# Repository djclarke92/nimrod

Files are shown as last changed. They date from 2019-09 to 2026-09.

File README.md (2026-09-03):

# Nimrod Home Automation

A home automation project based on the Raspberry Pi, Modbus IO devices and NodeMCU modules.  The control software is written in C++ and the web configuration is in PHP7.  Relies on 
a MySQL database running on a separate host.  The current software is compiled for Pi model B running the Rasbian buster release.

Why call it Nimrod ?  It needed a name and "Nimrod" was the name of a neanderthal butler in an early Doctor Who episode. The original purpose was to develop something to turn on my
motorbike glove heater 30 minutes before my morning alarm went off if the outside temperature was below 15 deg C.

The Nimrod software is compiled on your standard linux desktop PC, then cross compiled for the Pi version your are using.  In theory you could compile everything on the Pi and 
do away with the cross compiler step.

Uses dygraph.js from http://dygraphs.com for displaying graphs. Websocket support comes from https://libwebsockets.org/.

What can you do with it ?
* Input events can be switches, temperature values, voltage levels or time of day
* Turn on one or more output ports when an input event occurs
* Input switch events can be a click, double click or long click, each can trigger different output actions
* Input events can be chained together, e.g. if time is 6:30am and temperature sensor #2 is < 15 deg then turn on output #7 for 30 minutes
* Complex processes can be managed by the integratd PLC State Machine

Communication with each modbus device is polled.  All digital inputs are active low, i.e. connect to 0V / Gnd to activate.  All digital outputs are active low open collector outputs.

On a Pi4, we recommend that you move the /var file system onto a USB3 hard drive otherwise the Pi's uSDHC card will die quite soon due to the number of writes. 

The Nimrod web page also supports displaying CCTV camera images and video streams, to do this you need the mount the CCTV image storage filesystem onto the Pi (edit /etc/fstab and 
create /etc/.smbpwd).  The camera definitions are in the file/site_config.conf file.
1.	/etc/fstab example
	//<SERVER_IP_ADDRESS>/cctv  /cctv   cifs    auto,gid=users,file_mode=0660,dir_mode=0660,iocharset=utf8,credentials=/etc/.smbpwd  0 0
2.	/etc/.smbpwd example, mode must be 0600
	username=<some_user_name>
	password=<some_password>
	domain=YOURSMBWORKGROUP

Note that for each server using a guest account, you may wish to specify an additional share in /etc/samba/smb.conf
thus;

[cctv]
        comment = cctv
        inherit acls = Yes
        path = /cctv
        read only = No
        vfs objects =
[cctv2]
        comment = cctv2
        inherit acls = Yes
        path = /cctv
        read only = No
        vfs objects =

Add a share for each additional server that will connect using the same account. In /etc/fstab, specifiy the new share name for each additional server
//<SERVER_IP_ADDRESS/cctv2, etc

This works around some Windows/samba peculiarities and allows conflict-free file/directory access.

Alternatively, you could use NFS instead, if you aren't using Windows PC's to access the camera files.

## Devices, Device Info and IO Links

Each Modbus interface device is called a "Device" in Nimrod speak.  So a "Device" could be a 16 digital input unit, 8 relay output unit, 8 analog voltage input unit, etc.

Once you have define a device you need to tell Nimrod what each of it's ports is connected to, this is called the "Device Info".  So for a 16DI unit you would setup input channel 1 is 
"Kitchen switch 1", input channel 2 is "Lounge switch 1", etc. The actual connections are determined by the physical cabling between the switch and the Modbus device.  Output devices 
are similarly defined, e.g. 8RO device channel #4 is "Carport Lights".

Now that you have defined the inputs and outputs you need to tell Nimrod how to connect them together.  This is called "IO Links".  E.g. "Kitchen switch 1" links to 
"Carport Lights", and you can also specify if the output is on until the switch is pressed again or automatically turns off after a set time.

## Supported Modbus devices

Modbus RS485 devices from Wellpro and others

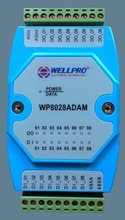
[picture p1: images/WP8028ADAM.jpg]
WP8028ADAM device


* WP3066ADAM		8DS18B20 - 8x DS18B20 temperature inputs
* WP3082ADAM		8AI - 8x 0-20mA / 4-20mA analog inputs
* WP3084ADAM		8VI - 8x 0-10V DC analog inputs
* WP8025ADAM		8RO - 8x relay outputs
* WP8026ADAM		16DI - 16x digital inputs
* WP8027ADAM		16DO - 16x digital outputs
* WP8028ADAM		8DI/8DO - 8x digital outputs, 8x digital inputs
* PD3064			8KT - 8 K Thermocouples
* HDL300			Submersible water level sensor

## Supported WiFi devices

* NodeMCU (ESP8266)
	modules - adc crypto enduser_setup file gpio http net node pwm tmr uart websocket wifi + TLS

# Nimrod package file structure
* ./LICENSE							GNU v3 license
* ./README.md						This file
* ./RELEASE-NOTES.TXT				A history of changes to Nimrod
* ./index.php						Nimrod web portal home page
* ./favicon.ico						Favicon file
* ./bin/nimrod						Nimrod server executable (amd64)
* ./bin/nimrod-arm7					Nimrod server executable (arm7)
* ./bin/set-address					Set the Modbus device index (amd64)
* ./bin/set-address-arm7			Set the Modbus device index (arm7)
* ./files/cameras.php				Shows CCTV camera snapshots on the Nimrod web console
* ./files/class.email.php
* ./files/common.php				Base configuration and some common functions
* ./files/commonhtml.php			Common functions which include HTML output.
* ./files/deviceinfo.php
* ./files/devices.php
* ./files/dygraph.js				Javascript graphing lib
* ./files/dygraph.css				Javascript graphing lib
* ./files/dygraph.min.js			Javascript graphing lib
* ./files/events.php				ToDo
* ./files/home.php
* ./files/intro.php					What is Nimrod
* ./files/monitor.php				Full screen monitor pages 1 and 2
* ./files/iolinks.php
* ./files/site_config.php
* ./files/site_config.php.sample	Example site config file
* ./files/styles.css
* ./images/*						Various image files to make Nimrod look good
* ./scripts/tables.sql				MySQL table creation sql script
* ./scripts/build-num.sh			Update the build number automatically each time makerelease.sh is run
* ./scripts/makerelease.sh			Create a new nimrod package
* ./scripts/nimrod.service			Exampe Nimrod service file of the Pi
* ./scripts/archive_cctv.sh			Script to delete old cctv files
* ./sounds/alerts.mp3
* ./sounds/warning1.mp3
* ./cctv -> /var/cctv				Symlink to your cctv images storage directory
* ./uploads							Create this directory manually and change the owner:group to www-data:www-data

# Raspberry Pi Model 4

## Create Pi bootable SD card

We recommend 16GB SD cards are used, an 8GB card is likely to run out of space in the future.

1.	umount /dev/sdd1
2.	dd bs=4M if=2019-07-10-raspbian-buster.img of=/dev/sdd
3.	boot the pi
	
## Initial Setup of the Pi

- Menu - Pi Configuration
	- System Tab
	- Expand Filesystem
	- Change password for pi user to something new (default is raspberry, nimrod default is passw0rd.23)
	- set hostname to nimrod (or nimrod2, nimrod3, etc)
	- Disable auto login 
- Interfaces Tab
	- Enable SSH
- Localization
	- Set Locale to EN / NZ
	- Set Timezone to Pacific/Auckland
	- Set Keyboard to United States / English International
	- Set WiFi Country to NZ
- Reboot
- Set password for root > sudu su; passwd
- Set static IP address
- sudo vi /etc/dhcpcd.conf (add to the end of the file)
		interface eth0
	  		static ip_address=192.168.1.199/24
	  		static routers=<your_gateway_ip_address>	
	  		static domain_name_servers=<dns_ip_addres_1> <dns_ip_address_2>
	  			(NZ InspireNet DNS servers are 203.114.168.2 203.114.128.2)
- Reboot	
- apt-get update
- apt-get upgrade
- Reboot

## Create the nimrod user on the Pi

It is recommended that you use the same uid/gid for each user/group across your installation. The useradd/groupadd 
commands have options for this.

1.	> adduser nimrod
	- Set password to something
2.	Add nimrod user to the dialout group to give acces to the /dev/ttyUSB* devices
	> adduser nimrod dialout
3.	Add any public ssh keys to $HOME/.ssh/authorized_keys
4.	Create pub/priv key pair
	> ssh-keygen -t rsa
	- copy the public key to nimrod@<database_server>:~/.ssh/authorized_keys

## Install additional packages required by Nimrod on the Pi

- cmd line: sudo apt-get update (update list of available packages)
- gui: sudo aptitude
- example to install curl
	- apt-cache search curl
	- apt-get install curl

Raspbian buster
- apache2 libapache2-mod-php php php-mysql php-gd
- libmodbus5 libmodbus-dev
- libssl-dev libusb-dev ntpddate
- mariadb-server
- mariadb-client libmariadb-dev
- (old mysql-client libmysqlclient-dev)
- msmtp msmtp-mta mailutils
- libwebsockets8 libwebsockets-dev libwebsockets-test-server
- gparted vsftpd

- Secure the mariadb installation
> sudo mysql_secure_installation

- Enable mod-ssl in apache using a self signed certificate
> sudo a2enmod ssl
> sudo a2ensite default-ssl
> sudo systemctl restart apache2

- Remove the default index.html file
> sudo rm /var/www/html/index.html

- make apache a member of the nimrod group
> sudo adduser www-data nimrod

## remove the swap file from the SD card

> sudo dphys-swapfile swapoff
> sudo dphys-swapfile uninstall
> sudo update-rc.d dphys-swapfile remove

## Move the /var directory onto a USB3 drive

- Once you transfer /var onto the USB3 drive the Pi will not boot without the USB3 drive connected
- Don't try and connect a second USB drive, the Pi4 can't cope with that
- Connect and the USB3 drive, format a large ext4 partition and a smaller swap partition
> sudo gparted

- Get the partition uuid's
> sudo blkid /dev/sda1
> sudo blkid /dev/sda2

- Edit the /etc/fstab to add in the new partitions
> sudo vi /etc/fstab
  # /dev/sda1
  PARTUUID=9ee98a25-97e4-xxxx-xxxx-dd0a23e1f247   swap    swap    defaults        0       0
  # /dev/sda2
  PARTUUID=51b819e6-8fd1-xxxx-xxxx-7ffbb871917e   /var    ext4    defaults        0       2
  
- Mount the new var partition and copy the files across
> sudo mount /dev/sda2 /mnt
> sudo rsync -axov /var/* /mnt

- Reboot and your /var partition and swap are on the USB3 drive
> sudo reboot

## Setup msmtp mail on the Pi

> sudo vi /etc/msmtprc
	# Set default values for all following accounts.
	defaults
	logfile /var/tmp/msmtp.log

	# Use the mail submission port 587 instead of the SMTP port 25.
	port 465

	# Always use TLS.
	tls on
	tls_starttls off

	# Set a list of trusted CAs for TLS. The default is to use system settings, but
	# you can select your own file.
	tls_trust_file /etc/ssl/certs/ca-certificates.crt

	# If you select your own file, you should also use the tls_crl_file command to
	# check for revoked certificates, but unfortunately getting revocation lists and
	# keeping them up to date is not straightforward.
	#tls_crl_file ~/.tls-crls

	# Mail account
	# TODO: Use the users username, e.g. root for system and pi for your raspbian user
	account pi

	# Host name of the SMTP server
	# TODO: Use the host of your own mail account
	host <your_isp_mail_host>

	# As an alternative to tls_trust_file/tls_crl_file, you can use tls_fingerprint
	# to pin a single certificate. You have to update the fingerprint when the
	# server certificate changes, but an attacker cannot trick you into accepting
	# a fraudulent certificate. Get the fingerprint with
	# $ msmtp --serverinfo --tls --tls-certcheck=off --host=smtp.freemail.example
	#tls_fingerprint 00:11:22:33:44:55:66:77:88:99:AA:BB:CC:DD:EE:FF:00:11:22:33
	
	# Envelope-from address
	# TODO: Use your own mail address
	from <pi_hostname>@<your_domain>
	
	# Authentication. The password is given using one of five methods, see below.
	auth on
	
	# TODO: Use your own user name for the mail account
	user pi@<your_domain>
	
	# Password method 1: Add the password to the system keyring, and let msmtp get
	# it automatically. To set the keyring password using Gnome's libsecret:
	# $ secret-tool store --label=msmtp \
	#   host smtp.freemail.example \
	#   service smtp \
	#   user joe.smith
	
	# Password method 2: Store the password in an encrypted file, and tell msmtp
	# which command to use to decrypt it. This is usually used with GnuPG, as in
	# this example. Usually gpg-agent will ask once for the decryption password.
	#passwordeval gpg2 --no-tty -q -d ~/.msmtp-password.gpg
	
	# Password method 3: Store the password directly in this file. Usually it is not
	# a good idea to store passwords in plain text files. If you do it anyway, at
	# least make sure that this file can only be read by yourself.
	# TODO: Use the password of your own mail account
	password <email_password>
	
	# Password method 4: Store the password in ~/.netrc. This method is probably not
	# relevant anymore.
	
	# Password method 5: Do not specify a password. Msmtp will then prompt you for
	# it. This means you need to be able to type into a terminal when msmtp runs.
	
	# Set a default account
	# TODO: Use the same account you've configured under account, e.g. root or pi
	account default: pi
	
	# Map local users to mail addresses (for crontab)
	aliases /etc/aliases
	
> sudo chown pi:pi /etc/msmtprc
> sudo chmod 0600 /etc/msmtprc
> sudo chmod 0777 /var/tmp
  cp /etc/msmtprc ~/.msmtprc

> sudo vi /etc/aliases
	root: pi@<your_domain>
	default: pi@<your_domain>
	
> sudo vi /etc/mail.rc
	set sendmail="/usr/bin/msmtp -t"

## Create a certificate so NodeMCU (ESP8266) WiFi devices can connect

> ssh nimrod@nimrod
> openssl req -x509 -nodes -days 3650 -newkey rsa:2048 -keyout nimrod-cert.key -out nimrod-cert.pem

# MySQL Database server

The MySQL database will contain the nimrod configuration and record events and monitoring data.
1.	Create nimrod user with password
2.	Create pub/priv key
	> ssh-keygen -t rsa
3.	Copy pub key to nimrod@pi
4.	Create nimrod database
5.	Create the nimrod tables
	
## Database username and password

If you want to change the default database username or password you need to edit the tables.sql and files/site_config.php files
to specify your required username and password before you create the tables. 
File:	./files/site_config.php			defines DB_USER_NAME and DB_PASSWORD
File:	./scripts/tables.sql			grant select,insert,update,delete on .......
	
## Database ssh tunnel

Nimrod sets up a tunnel to a remote mysql server as per the IP address in the site_config.php file. On the remote mysql host you need to add nimrod as a user and add 
the ssh keys for all nimrod hosts

# Installing Nimrod on the Pi into /var/www/html for the first time

1.	Copy the install tar file from your PC to the Pi
> scp nimrod-x.y.z.tgz nimrod@nimrod:/var/www/html/.
		
2.	Set permissions and untar the package as the nimrod user
> ssh nimrod@nimrod  
> sudo chown -R nimrod:nimrod /var/www/html  
> cd /var/www/html  
> tar xvzf nimrod.x.y.z.tgz  
> cp files/site_config.php.sample files/site_config.php  
> vi site_config.php  
	- set REMOTE_MYSQL_HOST and DB_PASSWORD
	
3.	Establish the SSH tunnel to the database host to accept the host key as the nimrod user
> ssh nimrod@REMOTE_DB_HOST  
> yes  
> ctrl-d		

4.	Create the guest user for camera ftp login
> adduser guest  
	- Set password to something (cameras will use guest/pwd to ftp videos to the server)
> add cctv symlink
	sudo su - guest
	cd /home/guest
	sudo mkdir /var/cctv .
	sudo mkdir /var/cctv/<camera_name>
	sudo chown -R guest:guest /var/cctv

4.	Apache2 setup
> Create the cctv symlink  
	cd /var/www/html  
	sudo ln -s /var/cctv cctv  
> Add apache to the guest group  
	sudo adduser www-data guest  
> Restart apache  
	sudo service apache2 restart

5.	Move the nimrod.log file onto /var/tmp
> cd /home/nimrod  
> sudo ln -s /var/tmp log  
> sudo vi /var/www/html/files/site_config.php
			
6.	Add nimrod to the guest group
> sudo adduser nimrod guest

7. create the web uploads directory
> sudo mkdir /var/www/html/uploads  
> sudo chown -R nimrod:nimrod /var/www/html  
> sudo chmod g+w /var/www/html/uploads

8.	Set nimrod to start automatically
> ssh pi@nimrod  
> cd /var/www/html  
> sudo cp scripts/nimrod.service.arm(7 or 64) /lib/systemd/system/nimrod.service  
> sudo chown root:root /lib/systemd/system/nimrod.service  
> sudo systemctl enable nimrod.service  
> sudo systemctl start nimrod

9.	Setup vsftpd if you have cameras attached so nimrod and apache can view the video files
> sudo vi /etc/vsftpd.conf  
  write_enable=YES  
  local_umask=002  
> sudo vi /home/guest/.bashrc  
  umask 002
  sudo systemctl restart vsftpd

10.	Nimrod should now be running

See the log in /home/nimrod/nimrod.log.  Point your browser to https://nimrod/index.php
	
11. Add a crontab entry for the nimrod user to archive old cctv files

> 20 4 * * * /home/nimrod/bin/archive_cctv.sh 2>&1

#Installing a signed ssl cert for apache2

See https://peppe8o.com/use-lets-encrypt-and-certbot-to-secure-raspberry-pi-hosted-websites-automatically/ for details
This gives you a 3 month signed certificate

> sudo apt update  
> sudo apt install snapd  
> sudo reboot  
> sudo snap install core  s
> sudo snap refresh core

># remove certbot if it is already installed
> sudo apt remove certbot

> sudo snap install --classic certbot  
> sudo ln -s /snap/bin/certbot /usr/bin/certbot  
> sudo certbot --apache -d <your_domain_name> -d www.<your_domain_name>

To renew the certificate use the following command
> sudo certbot renew

# Setup the cross compiler environment on your linux desktop PC

On your linux desktop PC:
> cd $HOME  
> mkdir raspberrypi  
> cd raspberrypi  
> rsync -rl --delete-after --copy-unsafe-links --progress pi@nimrod:/{lib,usr} $HOME/raspberrypi/rootfs

# Download the raspberrypi tools from github

cd $HOME/raspberrypi

> git clone https://github.com/raspberrypi/tools

# Download the raspberrypi documentation from github 

> git clone https://github.com/raspberrypi/documentation

- add to .bashrc
export PATH=$PATH:$HOME/raspberrypi/tools/arm-bcm2708/gcc-linaro-arm-linux-gnueabihf-raspbian/bin
	
Add gcc/g++ compiler packages to your desktop including 32bit gcc support packages, lib32gcc-6-dev, lib32z1

# Development and debugging

1.	A fairly verbose log file is written to /home/nimrod/nimrod.log
2.	Check the apache2 logs at /var/log/apache/error.log
3.	The nimrod application will automatically upgrade itself if it sees a nimrod.x.y.x.tgz package file in the /var/www/html directory
	To turn off the automatic upgrade feature, touch the file /var/www/html/no.upgrade
4.	The nimrod application will attempt to create an SSH tunnel to the remote MySQL database host on startup.
	To disable the SSH tunnel, touch the file /var/www/html/no.tunnel
5.	Each modbus device must be set with a unique address (1-254) using the set-address (or set-addres-arm7) tool. 
	A maximum of 254 devices are currently supported across any number of Pi's.  
	The baud rate for each modbus device should be set to 19200, the default is 9600, using the set-address tool.
6.	To build the software run the following command
	> ./scripts/makerelease.sh x.y.z ["nimrod_host1 [nimrod_host2]"] [copy]
	where "x.y.z" is the version number you are building,
	 	"nimrod_host1 nimrod_host2" is an optional space separated list of hosts to scp the successful package file onto,
	 	"copy" will just scp the existing package file, skipping the compile step

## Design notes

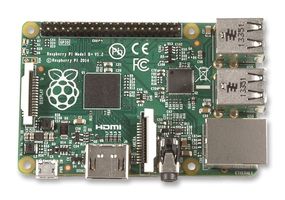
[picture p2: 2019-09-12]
images/raspberry-pi-b.jpg

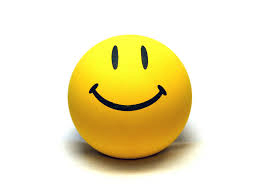
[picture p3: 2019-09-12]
images/smile.png

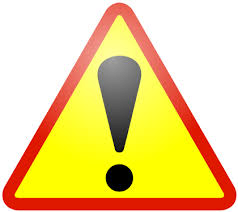
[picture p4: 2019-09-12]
images/warning.png

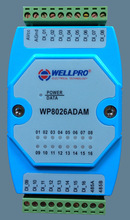
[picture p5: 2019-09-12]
images/WP8026ADAM.jpg

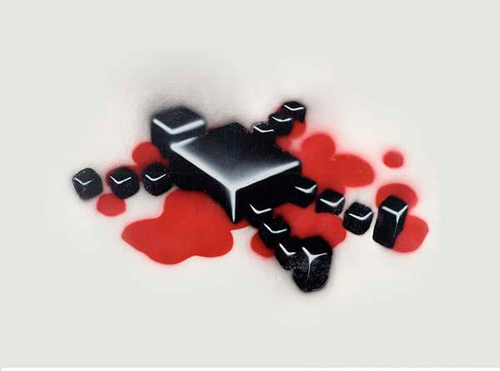
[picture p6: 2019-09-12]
images/buried_robot.png

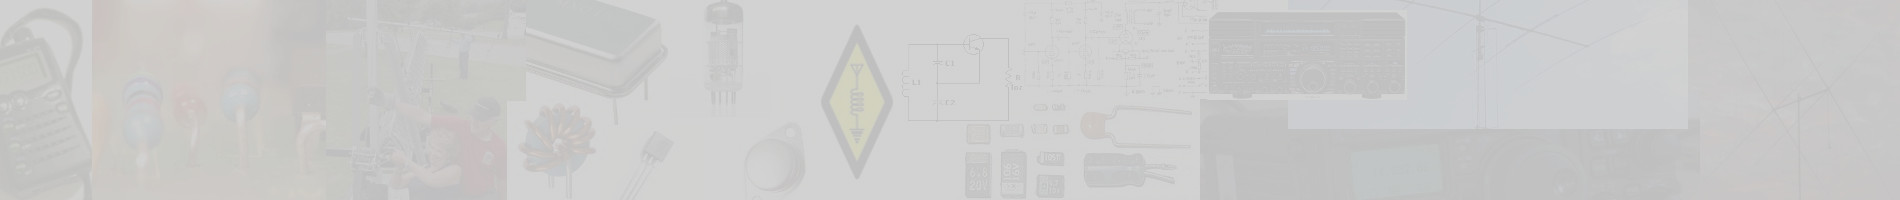
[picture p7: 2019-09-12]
images/background.jpg

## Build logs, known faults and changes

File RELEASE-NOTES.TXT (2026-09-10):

#-----------------------------------------------------------------------
#	Nimrod Automation System
#	Copyright (c) Dave Clarke
#	Author: Dave Clarke
#-----------------------------------------------------------------------

Nimrod Release Notes and History

Version 0.2.8		August 2026
1.	Add support for Holykell HPT604 liquid level sensor
2.	Add support for Holykell HRS10 tipping rain sensor
3.	Admin users can request the Nimrod service email the current log file to theie email address.	
4.	A remote nimrod service can now download an update package from a central server.	
5.	

Version 0.2.7		December 2025
1.	Add support for PT113MB load cell transmitter
2.	Add support for Adafruit ESP Matrix displays
3.	Add suppoort for weigh bridge including invoicing
4.	Add support for Systec IT1 weighing terminal
5.	Add support for thermal printer for weigh bridge printouts
6.	ssh -p 2223 -X -L 8443:localhost:443 <hostname>

Version 0.2.6		June 2025
1.	Fixing letsencrypt after an upgrade
 	sudo apt purge snapd
 	sudo reboot
 	sudo apt install snapd
 	sudo snap install core
 	sudo snap install certbot --classic
 	sudo certbot -d <domain_name>.co.nz --manual --preferred-challenges dns certonly
 	sudo setfacl -R -m u:nimrod:rX /etc/letsencrypt/{live,archive}/<domain_name>.co.nz
 	sudo setfacl -m u:nimrod:rX /etc/letsencrypt/{live,archive}
 	sudo systemctl restart nimrod
2.	Allow building remotely on raspberry Pi arm64

Version 0.2.5		Feb 2025
1.	Bug fixes to the Monitor pages re reviewing past data
2.	Improved PlcState buttons and layout
3.	Add websocket realtime updates of monitored voltage, current, temperature and levels on the Home page, Monitor pages and PLC State page
4.	Add NFlixen VSD control for iolinks and PLC states. VSD frequency can be adjusted during PLC operations
5.	New column il_VsdFrequency added to the iolinks table to support operating a VSD
6.	Use secure websockets with your LetsEncrypt certificates, run these commands to give the nimrod user access to the pem and key files.
	You will need to rerun these commands every 3 months after the cert is renewed.
	> sudo setfacl -R -m u:nimrod:rX /etc/letsencrypt/{live,archive}/<domain_name>.co.nz
	> sudo setfacl -m u:nimrod:rX /etc/letsencrypt/{live,archive}
7.	Add home page warning if the SSL certificate has expired or cannot be loaded.
8.	When using Letsencrypt certificates and certbot but the nimrod server is not accessible from the internet, manually get the cert using dns-01 challenge
	sudo certbot -d www.<domain_name>.co.nz --manual --preferred-challenges dns certonly
9.	RaspberryPI OS updated to bookworm in the Gitlab prebuilt packages
10.	Added support for SHT40 / XY-MD02 temperature / humidity sensor

Version 0.2.4		February 2023
1.	Add support for Variable Speed Drives (VSD) from NFlixen and Power Electronics
2.	Handle the case where some devices are powered off some of the time
3.	Fix code for html tooltips in BS5
4.	Allow PLC Operations and State Names to be copied and renamed
5.	Fix bug in retaining parameter changes on HDL-300 water level sensor
6.	Add support for HDHK 8 channel current meter

Version 0.2.3		July 2022
1.	Improvements and bug fixes to the PLC state handling
2.	Upgrade to JQuery 3.6.0 with map file
3.	Upgrade to Bootstrap 5.1.3 with map file
4.	Upgrade to popper 2.11.5 with map file
5.	Get websockets working over https/wss
6.	Fix bug in sending websockets messages
7.	Add Delay Keys to plcstates table to allow updating multiple records with the same delay value
8.	Add facility to clone a PLC Operation and delete an entire PLC Operation
9.	Handle PLC DelayTime as fractions of a second
10.	Improved websocket messaging

Version 0.2.2		June 2022
1.	Use a local copy of the bootstrap and jquery js and css files
2.	Prevent DeviceInof records from being deleted if they are linked to plcstate records
3.	Add timer events to the PLC state machine processing
4.	Add 'Reboot Camera' option to the cameras page
5.	Add autologin option in site_config.php, only from 127.0.0.1
6.	New E_IO_ON_OFF_INV input type for inverted state input
7.	New E_DT_CARD_READER added to support Proximity card readers and PIN pads
8.	New fields addded to the users table to support card readers - WIP
9.	Com ports like '/dev/ttyUSB*' are now stored in the devices table as '/dev/serial/by-path/...' to avoid port swapping issues after reboots

Version 0.2.1		Not released

Version 0.2.0		July 2021
1.	Added support for MT-52 series 12 bit multi turn rotary encoders
2.	Added support for ESP32 WiFi devices - 4 digial inputs, 4 digital outputs, 4 DS18B20 temperature sensors
3.	Added support for PZEM-016 AC V/I/W/F Monitor device, note this device only works at 9600 baud
4.	Allow each RS485 COM port to have a different baud rate, 9600 or 19200
5.	The events table ev_Value column type has changed to record the measured value in volts, deg C, etc instead of the sensor value
6.	Information on how to apply a signed certificate using snap and certbot

Version 0.1.8		May 2021
1.	Added the events page so you can view data from the events table for all or a specific device for a selected period.
2.	Schema changes to the deviceinfo table: di_Temperature and di_Voltage columns have been removed and functionality moved 
	to di_MonitorHi and di_MonitorLo
3.	Added new IO Types for monitoring Voltage or Temperature ranges, not just too high or too low
4.	Added support for the waterproof ultrasonic distance measurement module JSN-SR04T / AJ-SR04M for sensing water tank levels.
	The module interface is via TTL level RS-232.
5.	Added instructions for setting up msmtp mail as ssmtp is depreciated
6.	Create the cameras table to contain camera setup info rather than variables in site_config.php. The CAMERA variables in
	site_config.php can be deleted once you have upgraded to v0.1.8
7.	User login attempts are now saved to the events table with ev_DeviceNo=-3
8.	Failed login attempts are delayed by 4 seconds to slow any robot DOS attacks.
9.	Validate the username at login wihtout case sensitivity
10.	Info on how to install a free signed certificate for apache using certbot
11.	Improvements to the makefiles
12.	Added PLC State Machine code and PLC monitor page and plcstates table
13.	Added support for HDL300 type rs485 water level sensors

Version 0.1.7		November 2020
1.	Fixes to automatic database schema updates, you may need to create the 'conditions' table manually	
2.	Add new table "conditions" to allow multiple "AND" iolink conditions when decinding to take action on an event
	Note: any existing conditions must be reentered after upgrading to this version.
3.	Add historical cctv video file viewing to the 'Cameras' page
4.	Minor layout improvements to the web pages to support mobile and desktop devices
5.	Red colour highlighting on the home page if values are out of range or the value has not been recently updated
6.	Community contributed bug fixes, thanks Andrew F
	- Makefile.arm changes to reference ${HOME}
	- Typo fixed in cameras.php
	- Improvements to README.md
	- handle libmodbus version differences during compile

Version 0.1.6		October 2020
1.	Check the state of output device channels match the nimrod state and reset the state if necessary
2.	The files/site_config.php file has 2 new camera defines CAMERA_WEB_ROOT and CAMERA_FS_ROOT, see site_config.php.sample
3.	Database schema/data updates are now automatic, THIS_DATABASE_VERSION is defined in common.php
4.	Add control of PTZ cameras via image maps
5.	A number of minor layout changes to better support mobile devices
6.	Add camera refresh and cycle options
7.	Viewing camera files:
	- Create a cctv symlink under /var/www/html to where ever your camera files are stored (/var/cctv)
	- The guest user used by the cameras to ftp the video files needs a umask of 002 and all cctv files and directories need g+w permissions
	- Add the guest user group to the apache user
	- Most browsers cannot display mkv files by default, so these are now converted to mp4 format by ffmpeg before viewing

Version 0.1.5		September 2020
1.	Update set-address utility to handle PD30xx series devices (address and baud rate are in register 0x10)
2.	Fix SQL bug in deleting devices due to always finding deviceinfo and events records
3.	Brand new web interface based on bootstrap 4
4.	Add User Management page for authentication

Version 0.1.4		August 2020
1.	Do not use the ssh tunnel if the database is on localhost
2.	Database changes
2.1	Add 'users' table for login authentication - see tables.sql
	insert default admin record
2.2	Add columns to 'deviceinfo' table - see tables.sql
	di_MonitorPos
	di_MonitorHi
	di_MonitorLo
	di_ValueRangeHi
	di_ValueRangeLo
3.	Change graphing package to dygraph.js from dygraphs.com
4.	Add 2 Monitor pages to show multiple full screen graphs
5.	Handle PD3064 modbus devices supporting 8 K thermocouple inputs
6.	Automatically upgrade the nimrod software via usb stick, as /media/nimrod/<USB_STICK_LABEL>/nimrod-*.tgz
7.	Add better filtering of invalid temperatures values for DS18B20 devices

Version 0.1.3		July 2020
1.	Fix read timeout bug in processing output channels for devices with both inputs and outputs
2.	Display the package version on the nimrod home page 

Version 0.1.2		12/09/2019
1.	Code changes to support Raspbian buster and PHP7

Version 0.1.1		12/04/2015
1.	Initial release - so too many changes to mention !

....
The Nimrod Development Team

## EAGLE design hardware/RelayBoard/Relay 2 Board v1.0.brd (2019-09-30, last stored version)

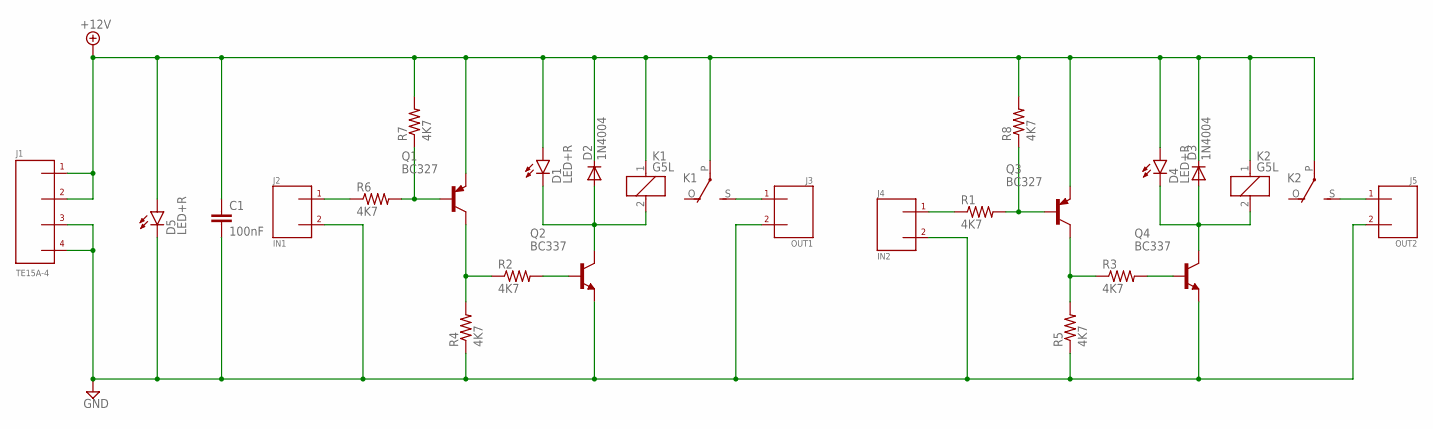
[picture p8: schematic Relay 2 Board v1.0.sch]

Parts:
C1: 100nF; CAP-PTH-5MM
D1, D4, D5: LED+R; LED3MM
D2, D3: 1N4004; DO41-10
J1: TE15A-4; J4-950MM
J2: IN1; J2V-508MM
J3: OUT1; J2V-508MM
J4: IN2; J2V-508MM
J5: OUT2; J2V-508MM
K1, K2: G5L; G5LE
Q1, Q3: BC327; TO92
Q2, Q4: BC337; TO92
R1, R2, R3, R4, R5, R6, R7, R8: 4K7; AXIAL-0.3

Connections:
+12V: C1.1, D1.A, D2.C, D3.C, D4.A, D5.A, J1.P$1 (1), J1.P$2 (2), K1.1, K1.P, K2.1, K2.P, Q1.1 (E), Q3.1 (E), R7.P$2 (2), R8.P$2 (2)
GND: C1.2, D5.K (C), J1.P$3 (3), J1.P$4 (4), J2.P$2, J3.P$2, J4.P$2, J5.P$2, Q2.1 (E), Q4.1 (E), R4.P$1 (1), R5.P$1 (1)
unnamed: Q3.2 (B), R1.P$2 (2), R8.P$1 (1)
unnamed: D1.K (C), D2.A, K1.2, Q2.3 (C)
unnamed: Q2.2 (B), R2.P$2 (2)
unnamed: Q1.3 (C), R2.P$1 (1), R4.P$2 (2)
unnamed: J5.P$1, K2.S
unnamed: Q1.2 (B), R6.P$2 (2), R7.P$1 (1)
unnamed: J2.P$1, R6.P$1 (1)
unnamed: J3.P$1, K1.S
unnamed: Q4.2 (B), R3.P$2 (2)
unnamed: Q3.3 (C), R3.P$1 (1), R5.P$2 (2)
unnamed: J4.P$1, R1.P$1 (1)
unnamed: D3.A, D4.K (C), K2.2, Q4.3 (C)

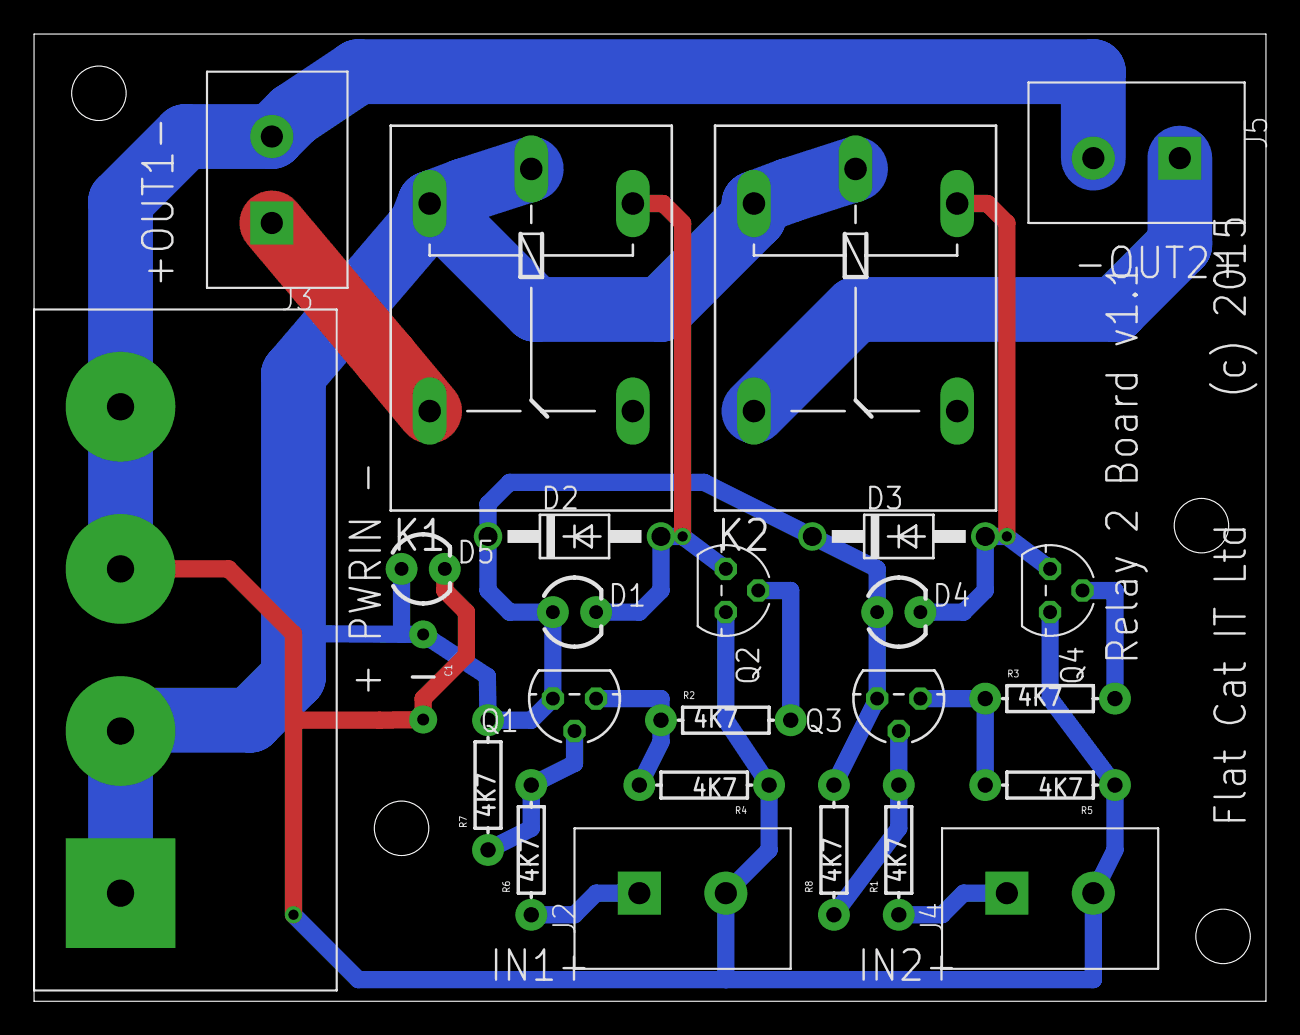
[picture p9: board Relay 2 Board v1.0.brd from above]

Board: 2 copper layers, 72.4 x 56.8 mm, 25 parts (0 on the bottom side), 14 nets.

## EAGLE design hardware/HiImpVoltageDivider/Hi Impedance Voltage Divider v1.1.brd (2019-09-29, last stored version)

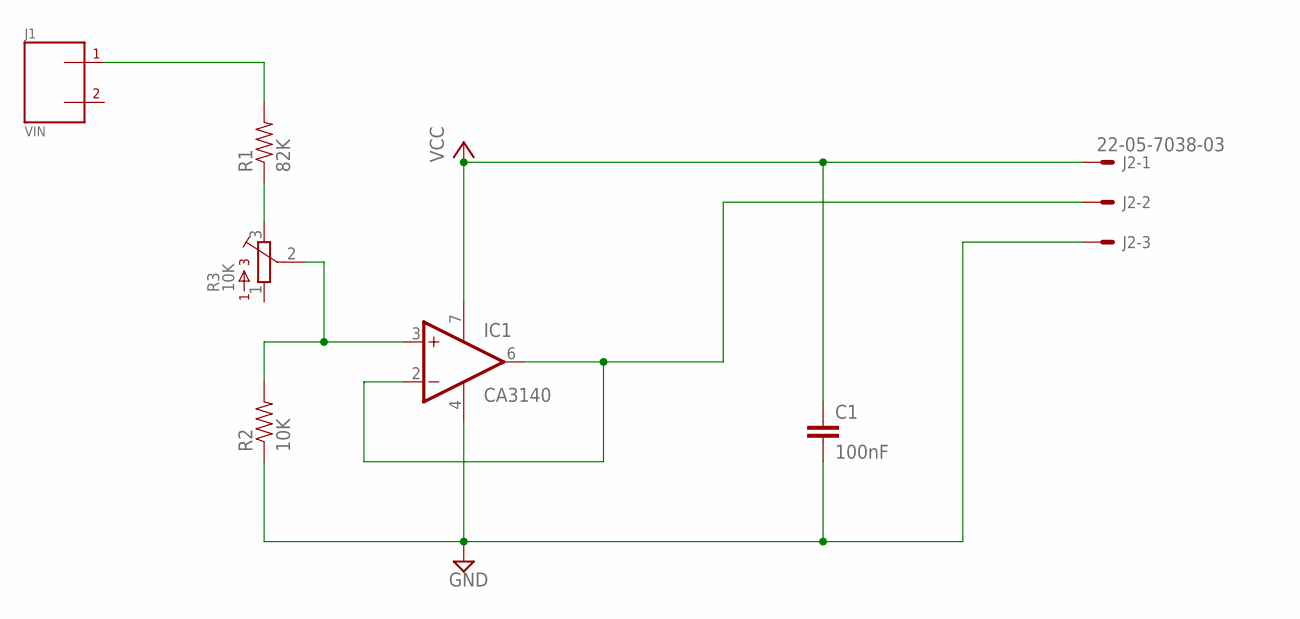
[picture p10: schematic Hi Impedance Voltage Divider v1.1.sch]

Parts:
C1: 100nF; CAP-PTH-5MM
IC1: CA3140; DIL08
J1: VIN; J2-508MM
J2: 22-05-7038-03; 7395-03
R1: 82K; AXIAL-0.3
R2: 10K; AXIAL-0.3
R3: 10K; 3386W

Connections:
GND: C1.2, IC1.4 (V-), J2.3, R2.P$1 (1)
unnamed: J1.P$1, R1.P$2 (2)
unnamed: R1.P$1 (1), R3.3
unnamed: IC1.3 (+IN), R2.P$2 (2), R3.2
unnamed: IC1.2 (-IN), IC1.6 (OUT), J2.2
VCC: C1.1, IC1.7 (V+), J2.1

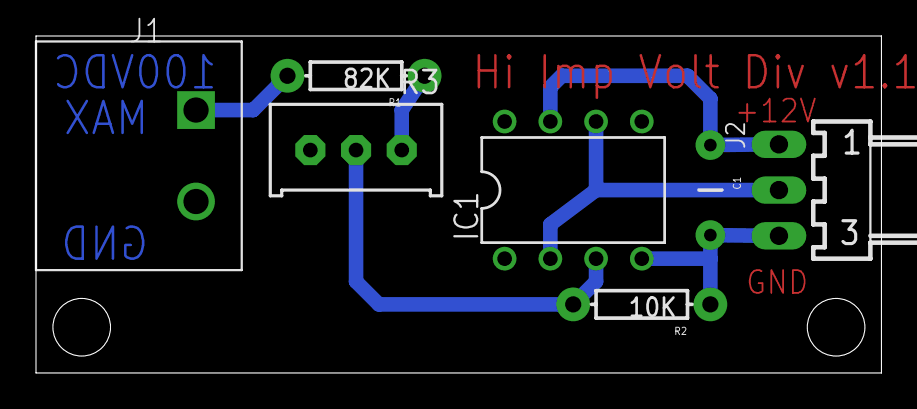
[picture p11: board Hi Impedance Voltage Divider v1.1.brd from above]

Board: 2 copper layers, 47.0 x 18.7 mm, 7 parts (0 on the bottom side), 6 nets.

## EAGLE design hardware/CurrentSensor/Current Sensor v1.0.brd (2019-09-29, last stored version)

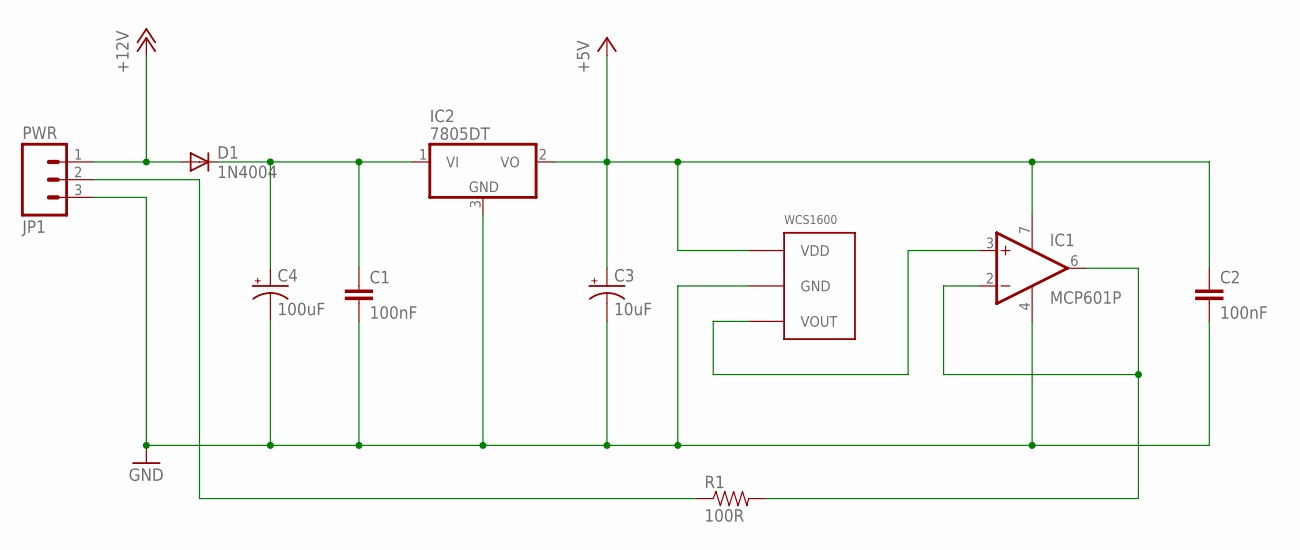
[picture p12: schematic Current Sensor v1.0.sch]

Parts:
C1, C2: 100nF; CAP-PTH-SMALL-KIT
C3: 10uF; CPOL-RADIAL-10UF-25V-KIT
C4: 100uF; CPOL-RADIAL-100UF-25V
D1: 1N4004; DO41-10
IC1: MCP601P; DIL08
IC2: 7805DT; TO252
JP1: PWR; MOLEX-1X3
R1: 100R; AXIAL-0.3
U$1: WCSXXXX

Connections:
+5V: C2.1, C3.1 (+), IC1.7 (V+), IC2.2 (VO), U$1.P$1 (VDD)
+12V: D1.A, JP1.1
GND: C1.2, C2.2, C3.2 (-), C4.2 (-), IC1.4 (V-), IC2.3 (GND), JP1.3, U$1.P$2 (GND)
unnamed: IC1.2 (-IN), IC1.6 (OUT), R1.P$2 (2)
unnamed: C1.1, C4.1 (+), D1.C, IC2.1 (VI)
unnamed: JP1.2, R1.P$1 (1)
unnamed: IC1.3 (+IN), U$1.P$3 (VOUT)

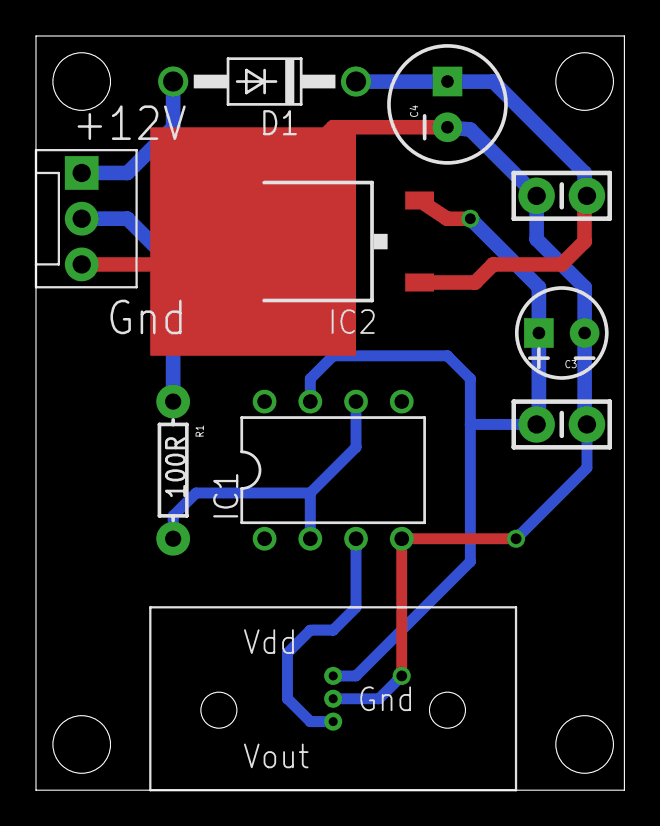
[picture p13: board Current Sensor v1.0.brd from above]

Board: 2 copper layers, 32.7 x 41.9 mm, 10 parts (0 on the bottom side), 7 nets.

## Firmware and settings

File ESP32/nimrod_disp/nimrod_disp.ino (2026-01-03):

#include <Arduino.h>
//#include "FS.h"
//#include "esp_system.h"
#include <esp_wifi.h>
#include <string.h>
#include <WiFi.h>
//#include <WiFiClientSecure.h>

#define ENABLE_DEBUG        // To enable debugging
#define ENABLE_ERROR_STRING // To show details in error
#define DEBUG_PORT Serial   // To define the serial port for debug printing
#include <ESP_SSLClient.h>
#include <WiFiClient.h>

#include <Preferences.h>  // WiFi storage
#include <Adafruit_Protomatter.h>
#include <Fonts/FreeSans9pt7b.h> // Large friendly font
#include <Fonts/FreeMono9pt7b.h> // Large friendly font

// matrix pins - waveshare matrix portsl S3
uint8_t rgbPins[]  = {42, 41, 40, 38, 39, 37};
uint8_t addrPins[] = {45, 36, 48, 35, 21};
uint8_t clockPin   = 2;
uint8_t latchPin   = 47;
uint8_t oePin      = 14;


     
//const char* gszSSID = NULL;  
//const char* gszPassword = NULL;
String gsPrefSSID;
String gsPrefPassword;
String gsPrefEspId;   // saved when wifi is setup, if 000 nimrod willl allocate an id
String gsPrefNimrodIp;
int giWFstatus = 255; //WL_IDLE_STATUS;
int giWiFiUpCount = 0;
int32_t giRssi = 0;  
String gsGetSsid;
String gsGetPass;
String gsMAC;
Preferences gPrefStorage;


// nimrod definitions
#define NIMROD_PORT       54011          // TODO: replace this with your own port number
#define PING_PERIOD       10
#define MSG_LENGTH        22
#define OUTPUT_LED_PIN    4
#define MSG_TIMEOUT       (20*1000)
bool gbDrawMatrix = true;
int giStartup = -1;
int giLedState = 0;
int giSocketConnected = -1;
int giSecSinceLastSend = 0;
int giSecSinceLastRecv = 0;
int giLedTimer = 20;
int giNumDevices = 0;
int giDisplayState = 0;
double gdWeight = 0;
int giHours = 0;
int giMinutes = 0;
int giSeconds = 0;
int giTimeCount = 0;
unsigned long gulNimrodLoopMillis = 0;
unsigned long gulLastMsgMillis = 0;
char gszCurrentTime[10] = "00:00:00";
String gsCardNo = "";
String gsTruckRego = "";
String gsTrailerRego = "";
String gsTruckTare = "";
String gsTrailerTare = "";
String gsTruckLoad = "";
double gdTruckWeight = 0.0;
String gsTrailerWeight = "";
//WiFiClientSecure client;
ESP_SSLClient ssl_client;

WiFiClient basic_client;


// end nimrod definitions

Adafruit_Protomatter matrix(
  128,          // Matrix width in pixels
  6,           // Bit depth -- 6 here provides maximum color options
  1, rgbPins,  // # of matrix chains, array of 6 RGB pins for each
  4, addrPins, // # of address pins (height is inferred), array of pins
  clockPin, latchPin, oePin, // Other matrix control pins
  true);       // HERE IS THE MAGIC FOR DOUBLE-BUFFERING!

// Sundry globals used for animation ---------------------------------------

int16_t  text1X;        // Current text position (X)
int16_t  text1Y;        // Current text position (Y)
int16_t  text1Min;      // Text pos. (X) when scrolled off left edge
char     str1[64];      // Buffer to hold scrolling message text
int16_t  text2X;        // Current text position (X)
int16_t  text2Y;        // Current text position (Y)
int16_t  text2Min;      // Text pos. (X) when scrolled off left edge
char     str2[64];      // Buffer to hold scrolling message text

int giLastMillis = 0;
uint16_t ww, hh;

void setup() 
{
  Serial.begin(115200);
  Serial.printf("\nNimrod ESP32 S3 starting\n");

  // Initialize matrix...
  ProtomatterStatus status = matrix.begin();
  Serial.print("Protomatter begin() status: ");
  Serial.println((int)status);
  if(status != PROTOMATTER_OK) {
    // DO NOT CONTINUE if matrix setup encountered an error.
    for(;;) {
      Serial.printf("Matrix setup error\n");
      delay(500);
    }
  }

    // Set up the scrolling message...
  sprintf(str1, "GTWB");
  sprintf(str2, "DRIVE ON");
  matrix.setFont(&FreeSans9pt7b); // Use nice bitmap font
  matrix.setTextWrap(false);           // Allow text off edge
  matrix.setTextColor(0xFFFF);         // White
  int16_t  x1, y1;
  //uint16_t w, h;
  matrix.getTextBounds(str1, 0, 0, &x1, &y1, &ww, &hh); // How big is it?
  text1Min = -ww; // All text is off left edge when it reaches this point
  text1X = 0; //matrix.width(); // Start off right edge
  text1Y = hh-1;//matrix.height() / 2 - (y1 + h / 2); // Center text vertically

  matrix.getTextBounds(str2, 0, 0, &x1, &y1, &ww, &hh); // How big is it?
  text2Min = -ww; // All text is off left edge when it reaches this point
  text2X = 0; //matrix.width(); // Start off right edge
  text2Y = matrix.height()-(y1+hh);

  matrix.setCursor(0,16);
  matrix.print("Startup");
  matrix.show();

  // Note: when making scrolling text like this, the setTextWrap(false)
  // call is REQUIRED (to allow text to go off the edge of the matrix),
  // AND it must be BEFORE the getTextBounds() call (or else that will
  // return the bounds of "wrapped" text).

  nimrodSetup();

  wifiInit();


  // ignore server ssl certificate verification
  ssl_client.setInsecure();
  //ssl_client.allowSelfSignedCerts();

  // Set the receive and transmit buffers size in bytes for memory allocation (512 to 16384).
  ssl_client.setBufferSizes(1024 /* rx */, 512 /* tx */);

  /** Call setDebugLevel(level) to set the debug
   * esp_ssl_debug_none = 0
   * esp_ssl_debug_error = 1
   * esp_ssl_debug_warn = 2
   * esp_ssl_debug_info = 3
   * esp_ssl_debug_dump = 4
   */
  ssl_client.setDebugLevel(1);

  // In case ESP32 WiFiClient, the session timeout should be set,
  // if the TCP session was kept alive because it was unable to detect the server disconnection.
  ssl_client.setSessionTimeout(120); // Set the timeout in seconds (>=120 seconds)

  // Assign the basic client to use in non-secure mode.
  ssl_client.setClient(&basic_client, false /* set enable SSL option to false */);

} 

void loop() 
{
  if ( gulNimrodLoopMillis + 100 < millis() )
  {
    gulNimrodLoopMillis = millis();

    // update time
    giTimeCount += 1;
    if ( giTimeCount >= 10 ) {
      gbDrawMatrix = true;
      giTimeCount = 0;
      giSeconds += 1;
      if ( giSeconds >= 60 ) {
        giSeconds = 0;
        giMinutes += 1;
        if ( giMinutes >= 60 ) {
          giMinutes = 0;
          giHours += 1;
          if ( giHours >= 24 ) {
            giHours = 0;
          }
        }
      }
    }

    nimrodLoop();

    if ( giDisplayState > 0 ) {
      if ( gulLastMsgMillis + MSG_TIMEOUT < millis() ){
        giDisplayState = 0;
        gbDrawMatrix = true;
      }
    }

    if ( giWFstatus != WiFi.status() )
    { // wifi status has changed
      giWFstatus = getWifiStatus();
    }
    
    if ( WiFi.status() != WL_CONNECTED ) 
    {  // WiFi DOWN
      if ( giWiFiUpCount == 0 )
      {
        Serial.printf("Starting Wifi...'%s'\n", gsPrefSSID.c_str() );
        
        WiFi.begin(gsPrefSSID.c_str(), gsPrefPassword.c_str());
        giWiFiUpCount += 1;
      }
      else if ( giWiFiUpCount > 200 )
      { // try again
        giWiFiUpCount = 0;
        
        Serial.printf("WiFi still not connected\n");
      }
      else
      {
        giWiFiUpCount += 1;
      }
    }  
  }

  if ( gbDrawMatrix )
  {
    gbDrawMatrix = false;

    drawMatrix();
  }
}  

void drawMatrix()
{
  char szLine[20];
  String sLine1;
  String sLine2;
  // Every frame, we clear the background and draw everything anew.
  // This happens "in the background" with double buffering, that's
  // why you don't see everything flicker. It requires double the RAM,
  // so it's not practical for every situation.

  matrix.fillScreen(0); // Fill background black

  switch ( giDisplayState ) {
  default:
  case 0:
    if ( giHours >= 19 || giHours < 6 ) {
      sLine1 = "";
      sLine2 = "";
      sprintf( gszCurrentTime, "%02d:%02d:%02d", giHours, giMinutes, giSeconds );
    } else {
      sLine1 = str1;
      //sLine2 = str2;
      if ( gdWeight >= 1000 )
        sprintf( szLine, "%d KG", (int)gdWeight );
      else
        sprintf( szLine, "%.1f KG", gdWeight );
      sLine2 = szLine;

      sprintf( gszCurrentTime, "%02d:%02d:%02d", giHours, giMinutes, giSeconds );
    }

    matrix.setTextColor(0xFFFF);         // White
    matrix.setCursor(text1X, text1Y);
    matrix.print(sLine1);

    matrix.setTextColor(matrix.color565(0xff,0x00,0x00)); 
    matrix.setCursor(58, 12);
    matrix.print(gszCurrentTime);

    matrix.setTextColor(matrix.color565(0x00,0x00,0xff)); 
    matrix.setCursor(text2X, text2Y);
    matrix.print(sLine2);
    break;

  case 1:
    // card disabled
    sLine1 = "#";
    sLine1 += gsCardNo;
    sLine2 = "DISABLED";

    matrix.setTextColor(0xFFFF);         // White
    matrix.setCursor(text1X, text1Y);
    matrix.print(sLine1);
    matrix.setTextColor(matrix.color565(0xff,0x00,0x00)); 
    matrix.setCursor(text2X, text2Y);
    matrix.print(sLine2);
    break;

  case 2:
    // card not found
    sLine1 = "#";
    sLine1 += gsCardNo;
    sLine2 = "NOT FOUND";

    matrix.setTextColor(0xFFFF);         // White
    matrix.setCursor(text1X, text1Y);
    matrix.print(sLine1);
    matrix.setTextColor(matrix.color565(0xff,0x00,0x00)); 
    matrix.setCursor(text2X, text2Y);
    matrix.print(sLine2);
    break;
    
  case 3:
    // card found
    sLine1 = "#";
    sLine1 += gsCardNo;
//    sLine2 = "DISABLED";

    matrix.setTextColor(0xFFFF);         // White
    matrix.setCursor(text1X, text1Y);
    matrix.print(sLine1);
//    matrix.setTextColor(matrix.color565(0x00,0x00,0xff)); 
//    matrix.setCursor(text2X, text2Y);
//    matrix.print(sLine2);
    break;
    
  case 4:
    // truck rego
    sLine1 = "#";
    sLine1 += gsCardNo;
    sLine2 = "REGO ";
    sLine2 += gsTruckRego;

    matrix.setTextColor(0xFFFF);         // White
    matrix.setCursor(text1X, text1Y);
    matrix.print(sLine1);
    matrix.setTextColor(matrix.color565(0x00,0x00,0xff)); // green
    matrix.setCursor(text2X, text2Y);
    matrix.print(sLine2);
    break;
    
  case 5:
    // truck tare
    sLine1 = "REGO ";
    sLine1 += gsTruckRego;
    sLine2 = "TARE ";
    sLine2 += gsTruckTare.toInt();
    sLine2 += " KG";

    matrix.setTextColor(0xFFFF);         // White
    matrix.setCursor(text1X, text1Y);
    matrix.print(sLine1);
    matrix.setTextColor(matrix.color565(0x00,0x00,0xff));   // green
    matrix.setCursor(text2X, text2Y);
    matrix.print(sLine2);
    break;
    
  case 6:
    // truck weight
    if ( gdTruckWeight >= 1000 )
      sprintf( szLine, "%d LOAD", (int)gdTruckWeight - gsTruckTare.toInt() );
    else
      sprintf( szLine, "%.1f LOAD", gdTruckWeight - (double)gsTruckTare.toInt() );
    sLine1 = szLine;
    if ( gdTruckWeight >= 1000 )
      sprintf( szLine, "%d WEIGHT", (int)gdTruckWeight );
    else
      sprintf( szLine, "%.1f WEIGHT", gdTruckWeight );
    sLine2 = szLine;

    if ( (double)gsTruckTare.toInt() + (double)gsTruckLoad.toInt() < gdTruckWeight)
      matrix.setTextColor(matrix.color565(0xff,0x00,0x00));   // red - overloaded
    else
      matrix.setTextColor(0xFFFF);         // White
    matrix.setCursor(text1X, text1Y);
    matrix.print(sLine1);

    if ( (double)gsTruckTare.toInt() + (double)gsTruckLoad.toInt() < gdTruckWeight)
      matrix.setTextColor(matrix.color565(0xff,0x00,0x00));   // red - overloaded
    else
      matrix.setTextColor(matrix.color565(0x00,0x00,0xff));   // green
    matrix.setCursor(text2X, text2Y);
    matrix.print(sLine2);
    break;
    
  case 7:
    // trailer rego
    sLine1 = "#";
    sLine1 += gsCardNo;
    sLine2 = "REGO ";
    sLine2 = gsTrailerRego;

    matrix.setTextColor(0xFFFF);         // White
    matrix.setCursor(text1X, text1Y);
    matrix.print(sLine1);
    matrix.setTextColor(matrix.color565(0x00,0x00,0xff));   //green
    matrix.setCursor(text2X, text2Y);
    matrix.print(sLine2);
    break;
    
  case 8:
    // trailer tare
    sLine1 = "REGO ";
    sLine1 += gsTrailerRego;
    sLine2 = "TARE ";
    sLine2 = gsTrailerTare.toInt();
    sLine2 += "KG";

    matrix.setTextColor(0xFFFF);         // White
    matrix.setCursor(text1X, text1Y);
    matrix.print(sLine1);
    matrix.setTextColor(matrix.color565(0x00,0x00,0xff));   // green
    matrix.setCursor(text2X, text2Y);
    matrix.print(sLine2);
    break;
    
  case 9:
    // trailer weight
    sLine1 = "REGO ";
    sLine1 += gsTrailerRego;
    sLine2 = "WEIGHT ";
    sLine2 = gsTrailerWeight.toInt();
    sLine2 += "KG";

    matrix.setTextColor(0xFFFF);         // White
    matrix.setCursor(text1X, text1Y);
    matrix.print(sLine1);
    matrix.setTextColor(matrix.color565(0x00,0x00,0xff));   // green
    matrix.setCursor(text2X, text2Y);
    matrix.print(sLine2);
    break;
    
  case 10:
    // trailer rego missing
    sLine1 = "TRAILER";
    //sLine1 += gsTrailerRego;
    sLine2 = "NO REGO";
    //sLine2 = gsTrailerWeight;

    matrix.setTextColor(0xFFFF);         // White
    matrix.setCursor(text1X, text1Y);
    matrix.print(sLine1);
    matrix.setTextColor(matrix.color565(0xff,0x00,0x00)); 
    matrix.setCursor(text2X, text2Y);
    matrix.print(sLine2);
    break;
    
  case 11:
    // already swiped
    sLine1 = "REGO ";
    sLine1 += gsTruckRego;
    sLine2 = "CARD IGNORED";
    //sLine2 = gsTrailerWeight;

    matrix.setTextColor(0xFFFF);         // White
    matrix.setCursor(text1X, text1Y);
    matrix.print(sLine1);
    matrix.setTextColor(matrix.color565(0xff,0x00,0x00)); 
    matrix.setCursor(text2X, text2Y);
    matrix.print(sLine2);
    break;
    
  case 12:
    // empty truck
    sLine1 = "REGO ";
    sLine1 += gsTruckRego;
    if ( gdTruckWeight >= 1000 )
      sprintf( szLine, "EMPTY %d KG", (int)gdTruckWeight );
    else
      sprintf( szLine, "EMPTY %.1f KG", gdTruckWeight );
    sLine2 = szLine;

    matrix.setTextColor(0xFFFF);         // White
    matrix.setCursor(text1X, text1Y);
    matrix.print(sLine1);
    matrix.setTextColor(matrix.color565(0xff,0x00,0x00)); 
    matrix.setCursor(text2X, text2Y);
    matrix.print(sLine2);
    break;
  }
  // AFTER DRAWING, A show() CALL IS REQUIRED TO UPDATE THE MATRIX!
  matrix.show();
}

void wifiInit() 
{
  WiFi.mode(WIFI_AP_STA);  // required to read NVR before WiFi.begin()

  // Open Preferences with "wifi" namespace. Namespace is limited to 15 chars
  gPrefStorage.begin("wifi", false);
  gsPrefSSID = gPrefStorage.getString("ssid", "none");  // NVS key ssid
  gsPrefPassword = gPrefStorage.getString("password", "none");  // NVS key password
  gsPrefEspId = gPrefStorage.getString("espid", "000");
  gsPrefNimrodIp = gPrefStorage.getString("nimrodip", "none");
  gPrefStorage.end();

  // keep from rewriting flash if not needed
  if (!checkPrefsStore())    
  { // NV and Prefs are different, setup with SmartConfig
    String sBuf;

    readSerialLine("Enter SSID", sBuf);
    gsPrefSSID = sBuf;
    Serial.printf("Got SSID '%s'\n", gsPrefSSID.c_str());

    sBuf = "";
    readSerialLine("Enter Password", sBuf);
    gsPrefPassword = sBuf;
    Serial.printf("Got Password '%s'\n", gsPrefPassword.c_str());

    sBuf = "";
    readSerialLine("Enter 3 Digit ESP Id", sBuf);
    gsPrefEspId = sBuf;
    Serial.printf("Got ESP Id '%s'\n", gsPrefEspId.c_str());

    sBuf = "";
    readSerialLine("Enter Nimrod Server IP", sBuf);
    gsPrefNimrodIp = sBuf;
    Serial.printf("Got Nimrod IP '%s'\n", gsPrefNimrodIp.c_str());

    // save the new wifi credentials
    gPrefStorage.begin("wifi", false);
    gPrefStorage.putString("ssid", gsPrefSSID);
    gPrefStorage.putString("password", gsPrefPassword);
    gPrefStorage.putString("espid", gsPrefEspId);
    gPrefStorage.putString("nimrodip", gsPrefNimrodIp);
    gPrefStorage.end();
    
    Serial.printf("Restarting\n");
    delay(3000);
    
    ESP.restart();  // reboot with new wifi configuration
  }


  Serial.printf( "WiFi starting\n" );
  WiFi.begin(gsPrefSSID.c_str(), gsPrefPassword.c_str());
  giWiFiUpCount += 1;
}  

void readSerialLine( const char* szMsg, String& sBuf )
{
  int iLoop = 0;

  while ( !Serial.available() )
  {
    iLoop += 1;
    if ( iLoop == 1 )
    {
      Serial.printf("\n%s\n", szMsg);
      Serial.printf("%s/%s/%s/%s\n", gsPrefSSID.c_str(), gsPrefPassword.c_str(), gsPrefEspId.c_str(), gsPrefNimrodIp.c_str());
    } 
    else if ( iLoop > 20 )
    {
      iLoop = 0;
    }
    else
    {
      Serial.printf(".");
    }
    delay(500);
  }

  sBuf = Serial.readString();
  sBuf.replace("\n","");
  sBuf.replace("\r","");
}

bool checkPrefsStore() 
{
  bool bRet = true;
  String prefssid, prefpass, prefespid, prefnimrodip;

  // Open Preferences with my-app namespace. Namespace name is limited to 15 chars
  gPrefStorage.begin("wifi", false);
  prefssid = gPrefStorage.getString("ssid", "none");  // NVS key ssid
  prefpass = gPrefStorage.getString("password", "none");  // NVS key password
  prefespid = gPrefStorage.getString("espid", "000");
  prefnimrodip = gPrefStorage.getString("nimrodip", "none");
  gPrefStorage.end();

  if (prefssid == "none" || prefssid == "" || prefpass == "none" || prefpass == "" || prefespid == "000" || prefespid == "" || prefnimrodip == "none" || prefnimrodip == "") 
  {
    bRet = false;
  }

  return bRet;
}

void PrintIPinfo() 
{
  gsGetSsid = WiFi.SSID();
  gsGetPass = WiFi.psk();
  giRssi = WiFi.RSSI();
  giWFstatus = getWifiStatus();
  gsMAC = WiFi.macAddress();

  Serial.printf("SSID '%s', %d dbm\n", gsGetSsid.c_str(), giRssi );
  Serial.printf("IP address: %s / %s\n", WiFi.localIP().toString().c_str(), WiFi.subnetMask().toString().c_str() );
  Serial.printf("Gateway IP: %s\n", WiFi.gatewayIP().toString().c_str() );
  Serial.printf("DNS: %s\n", WiFi.dnsIP().toString().c_str() );
  Serial.printf("MAC: %s\n", gsMAC.c_str() );
}

int getWifiStatus() 
{
  int WiFiStatus;
  
  WiFiStatus = WiFi.status();
  Serial.printf("Status %d", WiFiStatus);
  switch (WiFiStatus) 
  {
  default:
    Serial.printf(", WiFi UNKNOWN \n");
    break;
  case WL_IDLE_STATUS:     // 0
    Serial.printf(", WiFi IDLE \n");
    break;
  case WL_NO_SSID_AVAIL:    // 1
    Serial.printf(", NO SSID AVAIL \n");
    break;
  case WL_SCAN_COMPLETED:   // 2
    Serial.printf(", WiFi SCAN_COMPLETED \n");
    break;
  case WL_CONNECTED:        // 3
    Serial.printf(", WiFi CONNECTED \n");
    break;
  case WL_CONNECT_FAILED:   // 4
    Serial.printf(", WiFi WL_CONNECT FAILED\n");
    break;
  case WL_CONNECTION_LOST:  // 5
    Serial.printf(", WiFi CONNECTION LOST\n");
    WiFi.persistent(false);  // don't write FLASH
    break;
  case WL_DISCONNECTED:     // 6
    Serial.printf(", WiFi DISCONNECTED ==\n");
    WiFi.persistent(false);  // don't write FLASH when reconnecting
    break;
  }
  
  return WiFiStatus;
}


//**********************************************************************************************************
//
//  nimrod functions
//
//**********************************************************************************************************


void nimrodSetup()
{
  pinMode( OUTPUT_LED_PIN, OUTPUT );

  digitalWrite( OUTPUT_LED_PIN, HIGH );

}
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

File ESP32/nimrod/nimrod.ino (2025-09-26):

#include <Arduino.h>
//#include "FS.h"
//#include "esp_system.h"
#include <esp_wifi.h>
#include <string.h>
#include <WiFi.h>
#include <Preferences.h>  // WiFi storage
#include <OneWire.h>
#include <DallasTemperature.h>

#define ENABLE_DEBUG        // To enable debugging
#define ENABLE_ERROR_STRING // To show details in error
#define DEBUG_PORT Serial   // To define the serial port for debug printing
#include <ESP_SSLClient.h>
#include <WiFiClient.h>


//const char* gszSSID = NULL;  
//const char* gszPassword = NULL;
String gsPrefSSID;
String gsPrefPassword;
int giWFstatus = 255; //WL_IDLE_STATUS;
int giWiFiUpCount = 0;
int32_t giRssi = 0;  
String gsGetSsid;
String gsGetPass;
String gsMAC;
Preferences gPrefStorage;

// GPIO where the DS18B20 is connected to
const int oneWireBus = 4;     

// Setup a oneWire instance to communicate with any OneWire devices
OneWire oneWire(oneWireBus);

// Pass our oneWire reference to Dallas Temperature sensor 
DallasTemperature sensors(&oneWire);


// nimrod definitions
#define NIMROD_PORT  54011          // TODO: replace this with your own port number
#define NIMROD_IP  "192.168.0.1"    // TODO: replace this with the IP address of your nimrod server
#define PING_PERIOD   30
#define MSG_LENGTH   22
#define INPUT_1_PIN  25
#define INPUT_2_PIN  26
#define INPUT_3_PIN  27
#define INPUT_4_PIN  33
#define OUTPUT_LED_PIN   2
#define OUTPUT_1_PIN  16
#define OUTPUT_2_PIN  17
#define OUTPUT_3_PIN  18
#define OUTPUT_4_PIN  19
#define MAX_DEVICES   4
String sEspName = "ESP000"; // default to 000 - nimrod will allocate a unique number for us
int giStartup = -1;
int giButton1Changed = -1;
int giButton2Changed = -1;
int giButton3Changed = -1;
int giButton4Changed = -1;
int giLedState = 0;
int giSocketConnected = -1;
int giSecSinceLastSend = 0;
int giSecSinceLastRecv = 0;
int giSecSinceLastTemp[MAX_DEVICES] = { 0, 0, 0, 0 };
int giLedTimer = 20;
int giNumDevices = 0;
int giTempCount = 0;
int iOutput1Timer = -1;
int iOutput2Timer = -1;
int iOutput3Timer = -1;
int iOutput4Timer = -1;
int iOutput1Period = 10;  // seconds
int iOutput2Period = 30;  // seconds
int iOutput3Period = 30;  // seconds
int iOutput4Period = 30;  // seconds
int iOutput1State = LOW;
int iOutput2State = LOW;
int iOutput3State = LOW;
int iOutput4State = LOW;
int giBtn1Active = 0;
int giBtn2Active = 0;
int giBtn3Active = 0;
int giBtn4Active = 0;
unsigned long gulLastLoopMillis = 0;
unsigned long gulBtn1Time = 0;
unsigned long gulBtn2Time = 0;
unsigned long gulBtn3Time = 0;
unsigned long gulBtn4Time = 0;
float gfLastTemp[MAX_DEVICES] = { 0.0, 0.0, 0.0, 0.0 };
hw_timer_t * timer1 = NULL;
hw_timer_t * timer2 = NULL;
hw_timer_t * timer3 = NULL;
hw_timer_t * timer4 = NULL;

ESP_SSLClient ssl_client;

WiFiClient basic_client;

DeviceAddress wDeviceAddr;
// end nimrod definitions

void setup() 
{
  Serial.begin(115200);
  Serial.printf("\nNimrod ESP32 starting\n");

  // Start the DS18B20 sensor
  sensors.begin();
  
  nimrodSetup();

  wifiInit();

  // ignore server ssl certificate verification
  ssl_client.setInsecure();
  //ssl_client.allowSelfSignedCerts();

  // Set the receive and transmit buffers size in bytes for memory allocation (512 to 16384).
  ssl_client.setBufferSizes(1024 /* rx */, 512 /* tx */);

  /** Call setDebugLevel(level) to set the debug
   * esp_ssl_debug_none = 0
   * esp_ssl_debug_error = 1
   * esp_ssl_debug_warn = 2
   * esp_ssl_debug_info = 3
   * esp_ssl_debug_dump = 4
   */
  ssl_client.setDebugLevel(1);

  // In case ESP32 WiFiClient, the session timeout should be set,
  // if the TCP session was kept alive because it was unable to detect the server disconnection.
  ssl_client.setSessionTimeout(120); // Set the timeout in seconds (>=120 seconds)

  // Assign the basic client to use in non-secure mode.
  ssl_client.setClient(&basic_client, false /* set enable SSL option to false */);

} 

void loop() 
{
  if ( gulLastLoopMillis + 100 < millis() )
  {
    gulLastLoopMillis = millis();

    nimrodLoop();

    if ( giWFstatus != WiFi.status() )
    { // wifi status has changed
      giWFstatus = getWifiStatus();
    }
    
    if ( WiFi.status() != WL_CONNECTED ) 
    {  // WiFi DOWN
      if ( giWiFiUpCount == 0 )
      {
        Serial.printf("Starting Wifi...\n" );
        
        WiFi.begin(gsPrefSSID.c_str(), gsPrefPassword.c_str());
        giWiFiUpCount += 1;
      }
      else if ( giWiFiUpCount > 200 )
      { // try again
        giWiFiUpCount = 0;
        
        Serial.printf("WiFi still not connected\n");
      }
      else
      {
        giWiFiUpCount += 1;
      }
    }  
  }
}  

void wifiInit() 
{
  WiFi.mode(WIFI_AP_STA);  // required to read NVR before WiFi.begin()

  // load credentials from NVR, a little RTOS code here
//  wifi_config_t conf;
//  esp_wifi_get_config(WIFI_IF_STA, &conf);  // load wifi settings to struct comf
//  gszSSID = reinterpret_cast<const char*>(conf.sta.ssid);
//  gszPassword = reinterpret_cast<const char*>(conf.sta.password);

  // Open Preferences with "wifi" namespace. Namespace is limited to 15 chars
  gPrefStorage.begin("wifi", false);
  gsPrefSSID = gPrefStorage.getString("ssid", "none");  // NVS key ssid
  gsPrefPassword = gPrefStorage.getString("password", "none");  // NVS key password
  gPrefStorage.end();

  // keep from rewriting flash if not needed
  if (!checkPrefsStore())    
  { // NV and Prefs are different, setup with SmartConfig
    if (gsPrefSSID == "none")
    { // new wifi config
      //delay(10000);
      initSmartConfig();
      
      delay(3000);
      
      ESP.restart();  // reboot with new wifi configuration
    }
  }


  Serial.printf( "WiFi starting\n" );
  WiFi.begin(gsPrefSSID.c_str(), gsPrefPassword.c_str());
  giWiFiUpCount += 1;
}  

// match WiFi IDs in NVS to Pref store,  assumes WiFi.mode(WIFI_AP_STA);  was
// executed
bool checkPrefsStore() 
{
  bool bRet = true;
//  String NVssid, NVpass;
  String prefssid, prefpass;

//  NVssid = getSsidPass("ssid");
//  NVpass = getSsidPass("pass");

  // Open Preferences with my-app namespace. Namespace name is limited to 15
  // chars
  gPrefStorage.begin("wifi", false);
  prefssid = gPrefStorage.getString("ssid", "none");  // NVS key ssid
  prefpass = gPrefStorage.getString("password", "none");  // NVS key password
  gPrefStorage.end();

  if ( prefssid == "none" || prefssid == "" || prefpass == "none" || prefpass == "") 
  { // wifi creds are not setup
    bRet = false;
  }

  return bRet;
}
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

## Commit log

2019-09-14 Move camera definitions into site_config.conf file, update docs
2019-09-29 Update docs and add hardware PCB and SCH files for HiImpVoltageDivider and CurrentSensor
    [Current Sensor v1.0.brd, Current Sensor v1.0.sch, Hi Impedance Voltage Divider v1.1.brd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]
2019-09-30 Added 2 channel relay board BRD and SCH files
    [Relay 2 Board v1.0.brd, Relay 2 Board v1.0.sch]
2021-06-13 ESP32 code update
2022-06-28 fix bug with initial state of inverted swicth inputs
    [mb_devices.cpp]
2025-12-12 WIP: weigh bridge printout
2026-01-14 0.2.7: weigh bridge fixes
    [mb_devices.cpp]
2026-05-10 WIP: restart camera and set camera time
2026-09-17 WIP 0.2.8 release
    [Current Sensor v1.0.brd, Current Sensor v1.0.sch, Hi Impedance Voltage Divider v1.1.brd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]

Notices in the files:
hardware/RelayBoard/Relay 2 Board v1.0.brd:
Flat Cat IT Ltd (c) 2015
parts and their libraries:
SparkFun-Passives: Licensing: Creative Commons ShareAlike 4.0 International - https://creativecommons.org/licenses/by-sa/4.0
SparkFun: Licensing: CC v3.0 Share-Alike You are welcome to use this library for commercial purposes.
